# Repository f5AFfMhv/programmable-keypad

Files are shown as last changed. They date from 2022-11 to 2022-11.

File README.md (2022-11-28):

# Programmabe Keypad
This is keypad project which uses Arduino Pro Micro as keyboard emulator. Each button sends key press combination over USB which is mapped to some particular action on computer.

Some footprints in this project are custom ones. You will need to import [my footprints](https://github.com/f5AFfMhv/my-kicad-libraries) library into KiCad.

For more information about this project look at its instructables page:
* [Programmable Keypad Rev B](https://www.instructables.com/Programmable-Keypad-Rev-B/)
* [Programmable Keypad](https://www.instructables.com/Programmable-Keypad-1/)

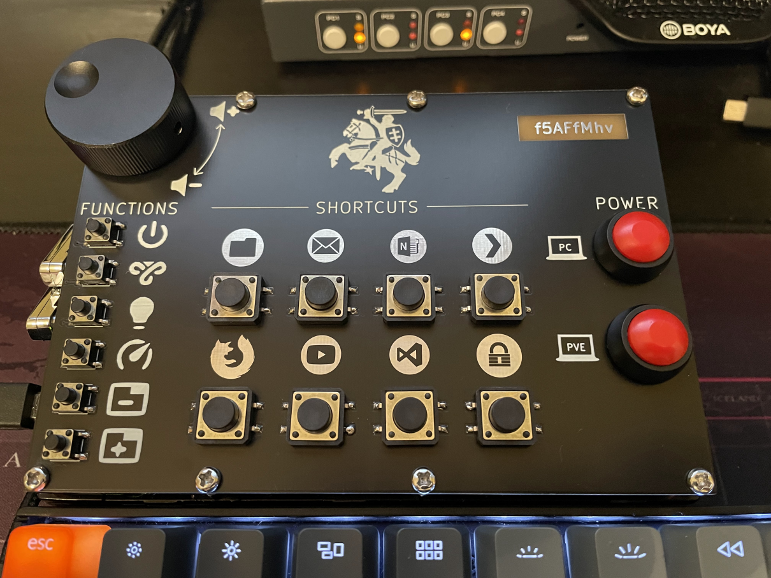
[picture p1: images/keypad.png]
keypad Keypad


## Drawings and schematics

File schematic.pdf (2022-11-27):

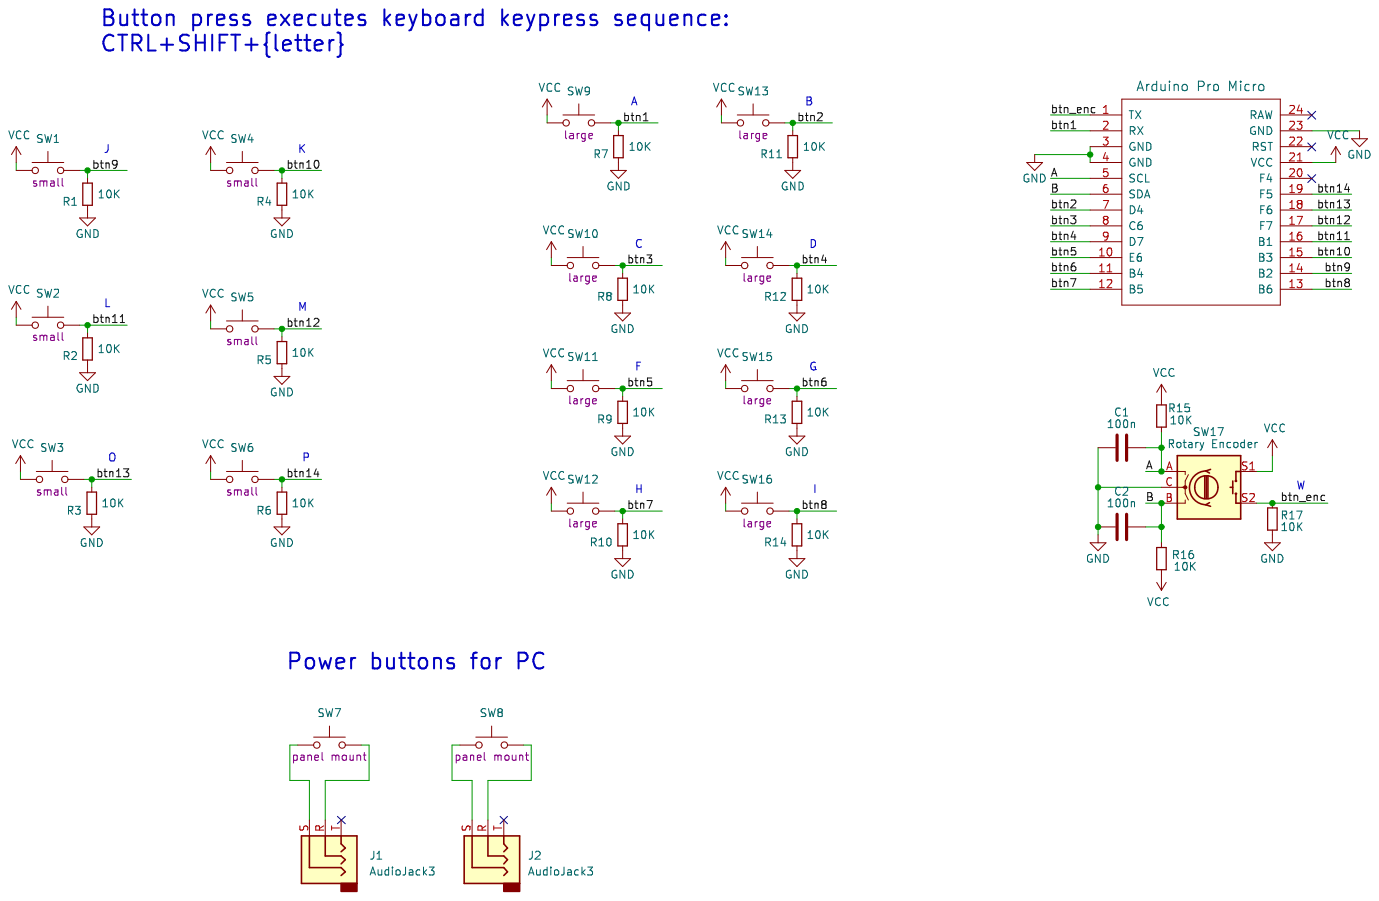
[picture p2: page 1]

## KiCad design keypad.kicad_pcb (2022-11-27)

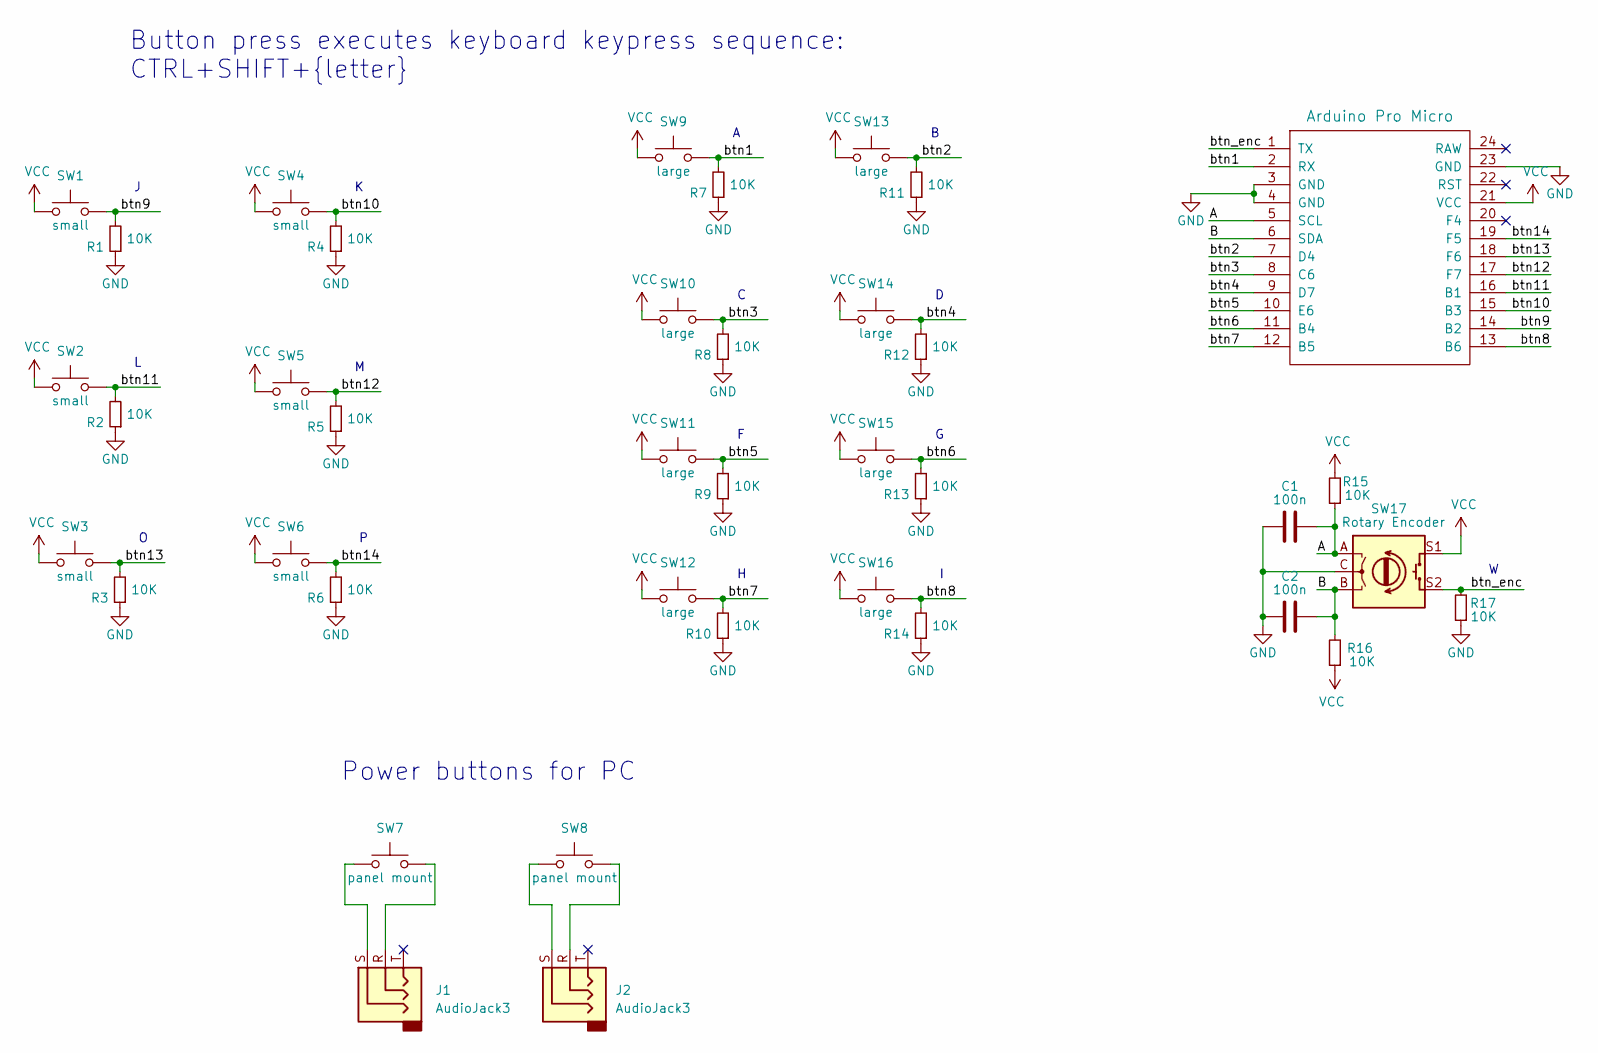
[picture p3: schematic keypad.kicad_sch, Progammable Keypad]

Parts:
C1, C2: 100n; C_0805_2012Metric
J1, J2: AudioJack3; Jack_3.5mm_custom-SMT_Horizontal
R1, R2, R3, R4, R5, R6, R7, R8, R9, R10, R11, R12, R13, R14, R15, R16, R17: 10K; R_0805_2012Metric
SW1, SW2, SW3, SW4, SW5, SW6: SW_Push; SW_SPST_PTS645
SW7, SW8: SW_Push; SW_SPST_button_panel-mount-12mm
SW9, SW10, SW11, SW12, SW13, SW14, SW15, SW16: SW_Push; SW_SPST_button_12x12_smd
SW17: Rotary Encoder; RotaryEncoder_custom
U1: Arduino Pro Micro; ProMicro-SMD

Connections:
/A: C1.1, R15.1, SW17.A, U1.5 (SCL)
/B: C2.1, R16.2, SW17.B, U1.6 (SDA)
/btn1: R7.2, SW9.2, U1.2 (RX)
/btn2: R11.2, SW13.2, U1.7 (D4)
/btn3: R8.2, SW10.2, U1.8 (C6)
/btn4: R12.2, SW14.2, U1.9 (D7)
/btn5: R9.2, SW11.2, U1.10 (E6)
/btn6: R13.2, SW15.2, U1.11 (B4)
/btn7: R10.2, SW12.2, U1.12 (B5)
/btn8: R14.2, SW16.2, U1.13 (B6)
/btn9: R1.2, SW1.2, U1.14 (B2)
/btn10: R4.2, SW4.2, U1.15 (B3)
/btn11: R2.2, SW2.2, U1.16 (B1)
/btn12: R5.2, SW5.2, U1.17 (F7)
/btn13: R3.2, SW3.2, U1.18 (F6)
/btn14: R6.2, SW6.2, U1.19 (F5)
/btn_enc: R17.2, SW17.S2, U1.1 (TX)
GND: C1.2, C2.2, R1.1, R2.1, R3.1, R4.1, R5.1, R6.1, R7.1, R8.1, R9.1, R10.1, R11.1, R12.1, R13.1, R14.1, R17.1, SW17.C, U1.3 (GND), U1.4 (GND), U1.23 (GND)
unnamed: J1.R, SW7.2
unnamed: J1.S, SW7.1
unnamed: J2.R, SW8.2
unnamed: J2.S, SW8.1
VCC: R15.2, R16.1, SW1.1, SW2.1, SW3.1, SW4.1, SW5.1, SW6.1, SW9.1, SW10.1, SW11.1, SW12.1, SW13.1, SW14.1, SW15.1, SW16.1, SW17.S1, U1.21 (VCC)

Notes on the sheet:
Button press executes keyboard keypress sequence: CTRL+SHIFT+{letter}
Power buttons for PC

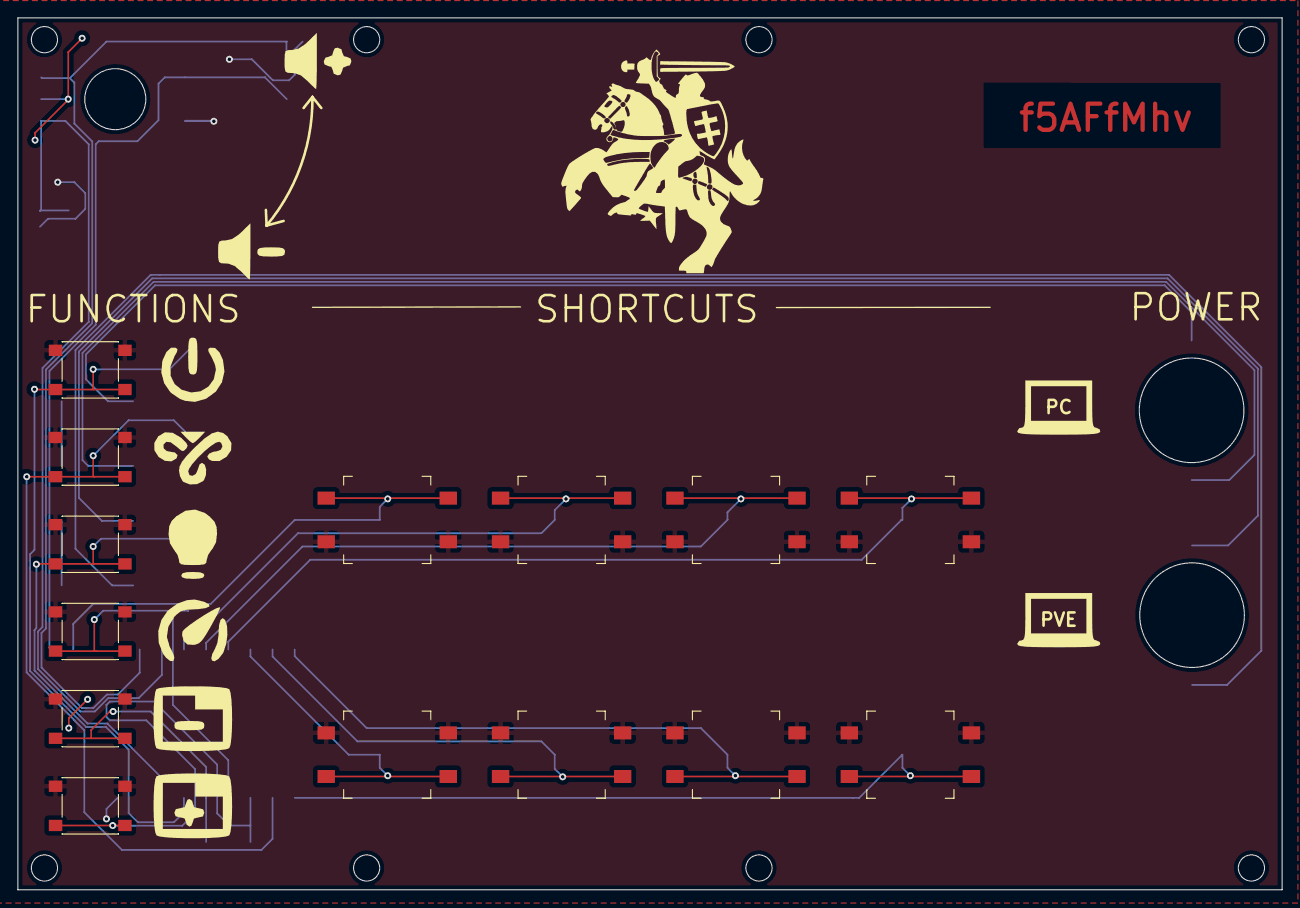
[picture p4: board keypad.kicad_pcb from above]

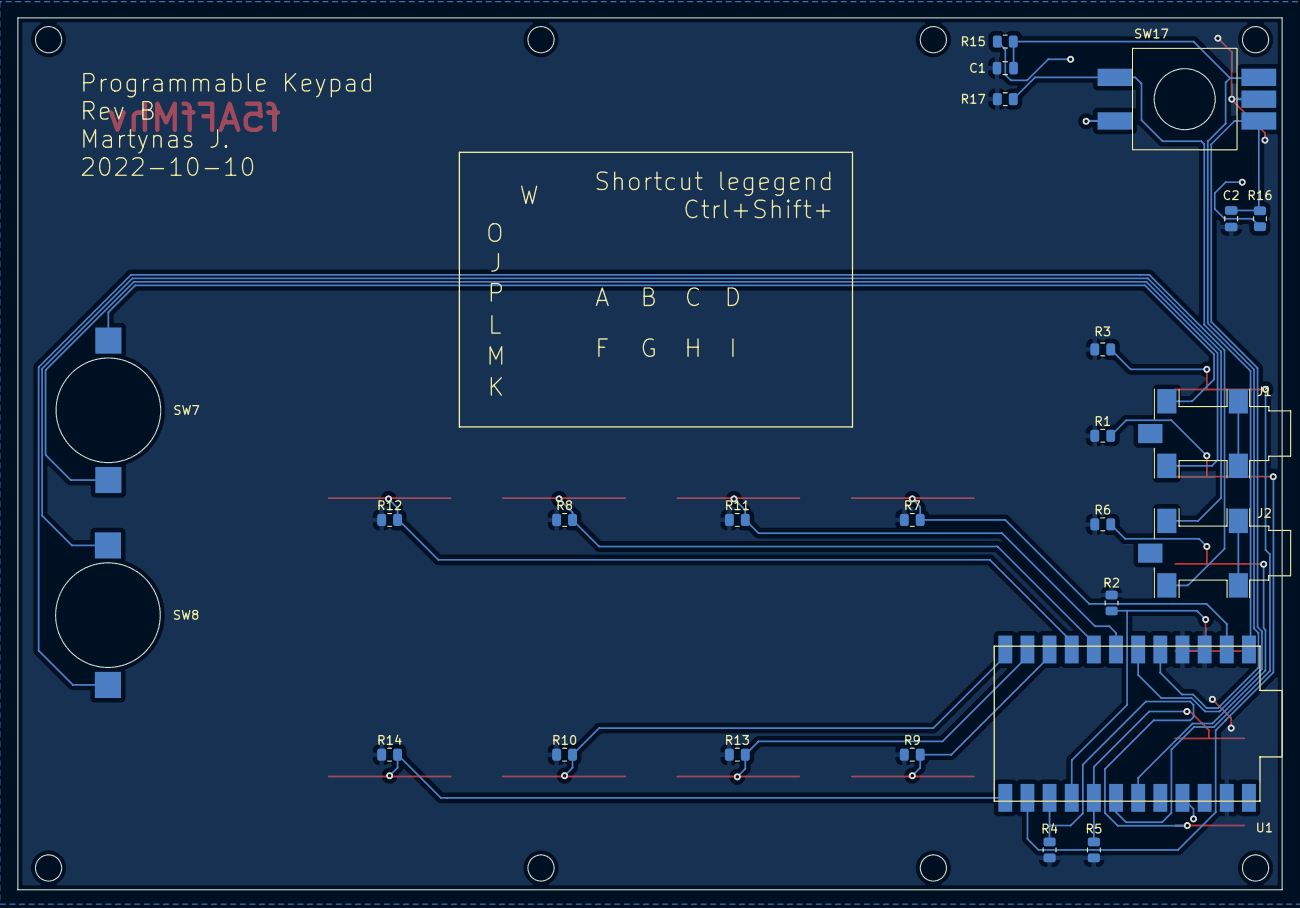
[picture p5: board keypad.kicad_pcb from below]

Board: 2 copper layers, 145.0 x 100.0 mm, 41 parts (22 on the bottom side), 23 nets.

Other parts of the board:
PC: LOGO; pc-symbol
PVE: LOGO; pc-symbol

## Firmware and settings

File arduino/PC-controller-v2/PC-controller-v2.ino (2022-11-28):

/*
  PC Controller with Keyboard Schortcuts

  For the Arduino Pro Micro.

  Sends keyboard schortcuts to PC

  created 2020-04-03
  by Martynas J.

v2.1
  Changed second rotary encoder function to work as window text size adjuster.
  It uses standard keypress combination which is understood by most of applications:
    Ctrl + + increase text size
    Ctrl + - decrease text size

  This code is in the public domain.

  https://github.com/f5AFfMhv
  https://www.instructables.com/member/f5AFfMhv/instructables/
  
*/

#include "Keyboard.h"
#include <Encoder.h>

/*        Arduino Pro Micro Pinout
           (PWM pins in brackets)
  
                   |﹉﹉|   
  TX    1     O--------------O RAW
  RX    0     O              O GND
          GND O              O RST
          GND O              O VCC
  SDA   2     O              O      21    A3
  SCL  (3)    O              O      20    A2
  A6    4     O              O      19    A1    
       (5)    O              O      18    A0
  A7   (6)    O              O      15    SCLK
        7     O              O      14    MISO
  A8    8     O   Pro Micro  O      16    MOSI
  A9   (9)    O______________O     (10)   A10
*/

#define ALL_BUTTONS 15
//        buttonID:   0  1  2  3  4  5  6  7  8   9   10  11  12  13  14
const int button[] = {1, 0, 4, 5, 6, 7, 8, 9, 10, 16, 14, 15, 18, 19, 20}; // pins for button inputs
Encoder myEnc(2, 3);    // rotary encoder pin A and B

int buttonState[ALL_BUTTONS] = {HIGH}; // state of each button in current cycle
int previousButtonState[ALL_BUTTONS] = {HIGH}; // state of each button in previous cycle

bool debugFlag = 1;            // flag for debug output over serial monitor
bool encoderButtonFlag = 0;    // for switching encoder functions

long oldPosition  = -999;     // for rotary encoder

void keyboard_shortcut(int buttonID);

void setup() {
  if (debugFlag) {
    //enable serial monitor
    Serial.begin(9600);
    Serial.println("Starting...");
  }
  // make the pushButton pins an input:
    for (int i=0;i<ALL_BUTTONS;i++) {
    pinMode(button[i], INPUT);
  }
  // initialize control over the keyboard:
  Keyboard.begin();
}

void loop() {
  // read the pushbuttons:
  for (int i=0;i<ALL_BUTTONS;i++) {
    buttonState[i] = digitalRead(button[i]);
    // if button pressed execute function with button ID:
    if ((buttonState[i] != previousButtonState[i]) && (buttonState[i] == HIGH)) {
      keyboard_shortcut(i); 
    }
    // save the current button state for comparison next time:
    previousButtonState[i] = buttonState[i];
  }
  // read the encoder
  long newPosition = myEnc.read();
  
  // check for encoder rotation
  if (newPosition != oldPosition) {
    if (newPosition > oldPosition) {
      if (encoderButtonFlag) {
        keyboard_shortcut(15);
      }
      else {
        keyboard_shortcut(16);
      }
    }
    else {
      if (encoderButtonFlag) {
        keyboard_shortcut(17);
      }
      else {
        keyboard_shortcut(18);
       }
    }
    oldPosition = newPosition;
    delay(200);
  }
}

void keyboard_shortcut(int buttonID) {
  // CTRL-SHIFT-x:
  Keyboard.press(KEY_LEFT_CTRL);
  Keyboard.press(KEY_LEFT_SHIFT);
  switch (buttonID) {
    case 0:
      Keyboard.press('w');
      encoderButtonFlag = !encoderButtonFlag; 
      if (debugFlag) {
        Serial.print("ENCODER_FLAG=");
        Serial.println(encoderButtonFlag);
      }
      break;
    case 1:
      Keyboard.press('A');
      break;
    case 2:
      Keyboard.press('B');
      break;
    case 3:
      Keyboard.press('C');
      break;
    case 4:
      Keyboard.press('D');
      break;
    case 5:
      Keyboard.press('F');
      break;
    case 6:
      Keyboard.press('G');
      break;
    case 7:
      Keyboard.press('H');
      break;
    case 8:
      Keyboard.press('I');
      break;
    case 9:
      Keyboard.press('J');
      break;
    case 10:
      Keyboard.press('K');
      break;
    case 11:
      Keyboard.press('L');
      break;
    case 12:
      Keyboard.press('M');
      break;
    case 13:
      Keyboard.press('O');
      break;
    case 14:
      Keyboard.press('P');
      break;
    case 15:
      Keyboard.release(KEY_LEFT_SHIFT);
      Keyboard.press('+');
      break;
    case 16:
      Keyboard.press('T');
      break;
    case 17:
      Keyboard.release(KEY_LEFT_SHIFT);
      Keyboard.press('-');
      break;
    case 18:
      Keyboard.press('V');
      break;
    default:
      break;
  }  
  delay(100);
  Keyboard.releaseAll();
  if (debugFlag) {
    Serial.print("Key pressed: ");
    Serial.println(buttonID);
  }
}

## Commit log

2022-11-27 add link too footprints
2022-11-28 change second encoder function
